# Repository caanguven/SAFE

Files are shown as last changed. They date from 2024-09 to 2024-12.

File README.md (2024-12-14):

# SAFE

Soft robots can adapt to dynamic environments where traditional rigid robots fall short. Existing soft quadruped robots lack effective remote control capabilities and often struggle with maintaining stable locomotion over long distances, limiting their practical application in real-world scenarios. This research addresses the challenges by improving the controllability and reliability of soft quadruped robots for use in search and rescue operations.

I developed the Soft Adaptive Field Explorer (SAFE), a tetherless soft quadruped robot equipped with onboard control interfaces and integrated sensors. A user-controlled web-based interface allows operators to interact with and control SAFE remotely. The integration of sensors such as cameras, inertial measurement units, and absolute rotary encoders optimizes gait performance through closed-loop feedback control. A comparative analysis of soft, rigid, and semi-soft leg materials evaluates their impact on stability, efficiency, and adaptability, identifying the optimal balance for diverse terrains.

This research demonstrates that incorporating the web-based interface and onboard sensor feedback improves the robot’s stability and navigational accuracy. By improving the adaptability and controllability of soft quadruped robots, this work bridges the gap between current soft robot capabilities and potential requirements for use in disaster response applications.

## Project Overview

The Advanced Quadruped project focuses on developing a robust and adaptable quadruped robot, SAFE, designed for challenging environments. The project includes the following key components:

- **Motor Control**: Utilizing Raspberry Pi and motor controllers to achieve precise movement and control of the quadruped's legs.
- **PID Control**: Implementing PID controllers to maintain stable locomotion and optimize gait performance.
- **Sensor Integration**: Incorporating various sensors such as cameras, IMUs, and rotary encoders to provide real-time feedback and enhance control accuracy.
- **Web-Based Interface**: Developing a user-friendly web interface for remote control and monitoring of the robot.

## Project Structure

The project is organized into the following directories and files:

### Directories

- **data_collect/**: Includes code used to collect data while operating the robot.
- **development/**: Includes an interface used at developemnt. By running the main.py you can access the main interface at port 5000. Using this interface we can access to various functionalies of SAFE. This is only for development purposes. Some codes might not work as expected.  
- **motor_controller_dev/**: Includes the directores that includes the motor controller such as square follow, April Tag detectino.
- **web_based_drive/**: Main teleoperated controller of the SAFE. Running main.py should start a fully functional Flask server that will provide IMU Camera and encoder data to user. This is the most optimzated way to operate SAFE. 

## Installation

To run this project, you need to have the following dependencies installed:

- `RPi.GPIO`
- `Adafruit_GPIO`
- `Adafruit_MCP3008`
- `solidpython`

You can install the required Python packages using pip. 

## Usage

To operate the SAFE robot, follow these steps:

1. **Setup**: Ensure all hardware components are properly connected and powered on. Verify that the Raspberry Pi is connected to the same network as your control device.
2. **Start the Server**: Navigate to the `web_based_drive` directory and run `main.py` to start the Flask server.
    ```sh
    cd /path/to/web_based_drive
    python main.py
    ```
3. **Access the Interface**: Open a web browser and navigate to `http://<Raspberry_Pi_IP>:5000` to access the web-based control interface.
4. **Control the Robot**: Use the interface to control the robot's movements, monitor sensor data, and adjust settings as needed.

## Contributing

Contributions to the SAFE project are welcome. If you have suggestions for improvements or new features, please follow these steps:

1. Fork the repository.
2. Create a new branch for your feature or bugfix.
3. Commit your changes and push the branch to your fork.
4. Submit a pull request with a detailed description of your changes.

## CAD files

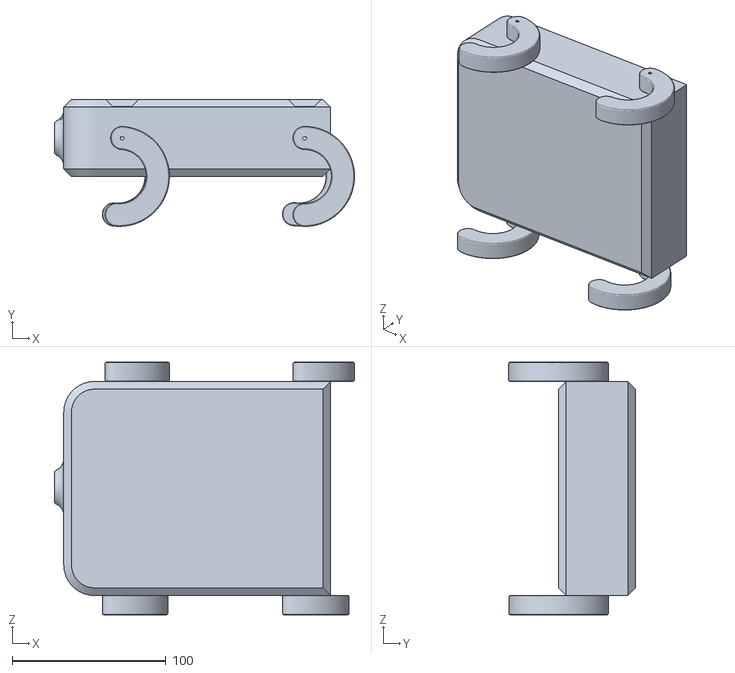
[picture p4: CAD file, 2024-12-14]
web_based_drive/static/model.stl
195.0 x 82.5 x 164.2

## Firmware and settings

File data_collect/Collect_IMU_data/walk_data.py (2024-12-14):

import warnings
import argparse
import sys
import logging
import math
import time
import signal
import os

import RPi.GPIO as GPIO
import busio
import board
import adafruit_bno08x
from adafruit_bno08x.i2c import BNO08X_I2C
import Adafruit_GPIO.SPI as SPI
import Adafruit_MCP3008
import threading

# Suppress specific warnings
warnings.filterwarnings("ignore", category=RuntimeWarning, module="adafruit_blinka.microcontroller.generic_linux.i2c")
warnings.filterwarnings("ignore", category=RuntimeWarning)

# Configure basic logging
logging.basicConfig(
    level=logging.INFO,
    format='%(message)s',
    handlers=[logging.StreamHandler()]
)

# Suppress GPIO warnings
GPIO.setwarnings(False)

# Constants for SPI and ADC
SPI_PORT = 0
SPI_DEVICE = 0
ADC_MAX = 1023
MIN_ANGLE = 0
MAX_ANGLE = 330
SAWTOOTH_PERIOD = 2  # Period in seconds

# GPIO Pins configuration (using BCM numbering)
# Motor 1 (Left Front)
MOTOR1_IN1 = 4
MOTOR1_IN2 = 7
MOTOR1_SPD = 24
MOTOR1_ADC_CHANNEL = 0

# Motor 2 (Right Front)
MOTOR2_IN1 = 5
MOTOR2_IN2 = 25
MOTOR2_SPD = 6
MOTOR2_ADC_CHANNEL = 1

# Motor 3 (Left Rear)
MOTOR3_IN1 = 17
MOTOR3_IN2 = 12
MOTOR3_SPD = 13
MOTOR3_ADC_CHANNEL = 2

# Motor 4 (Right Rear)
MOTOR4_IN1 = 18
MOTOR4_IN2 = 27
MOTOR4_SPD = 19
MOTOR4_ADC_CHANNEL = 3

class SpikeFilter:
    def __init__(self, name):
        self.filter_active = False
        self.last_valid_reading = None
        self.name = name

    def filter(self, new_value):
        if self.filter_active:
            if 150 <= new_value <= 700:
                return None
            else:
                self.filter_active = False
                self.last_valid_reading = new_value
                return new_value
        else:
            if self.last_valid_reading is not None and abs(self.last_valid_reading - new_value) > 300:
                self.filter_active = True
                return None
            else:
                self.last_valid_reading = new_value
                return new_value

    def reset(self):
        self.filter_active = False
        self.last_valid_reading = None

class PIDController:
    def __init__(self, Kp, Ki, Kd, name='PID'):
        self.Kp = Kp
        self.Ki = Ki
        self.Kd = Kd
        self.previous_error = 0
        self.integral = 0
        self.last_time = time.time()
        self.name = name

    def compute(self, error):
        current_time = time.time()
        delta_time = current_time - self.last_time
        if delta_time <= 0.0:
            delta_time = 0.0001

        proportional = self.Kp * error
        self.integral += error * delta_time
        integral = self.Ki * self.integral
        derivative = self.Kd * (error - self.previous_error) / delta_time

        control_signal = proportional + integral + derivative
        self.previous_error = error
        self.last_time = current_time

        return control_signal

    def reset(self):
        self.previous_error = 0
        self.integral = 0
        self.last_time = time.time()

class MotorController:
    def __init__(self, name, in1, in2, pwm, adc_channel, encoder_flipped=False):
        self.name = name
        self.in1 = in1
        self.in2 = in2
        self.pwm = pwm
        self.adc_channel = adc_channel
        self.position = 0
        self.last_valid_position = None
        self.pid = PIDController(Kp=0.8, Ki=0.1, Kd=0.05, name=f'PID-{self.name}')
        self.encoder_flipped = encoder_flipped
        self.spike_filter = SpikeFilter(name)

    def read_position(self, mcp):
        raw_value = mcp.read_adc(self.adc_channel)
        if self.encoder_flipped:
            raw_value = ADC_MAX - raw_value

        filtered_value = self.spike_filter.filter(raw_value)
        if filtered_value is None:
            return self.last_valid_position if self.last_valid_position is not None else 0

        degrees = (filtered_value / ADC_MAX) * 330.0
        self.last_valid_position = degrees
        return degrees

    def set_motor_direction(self, direction):
        if direction == 'forward':
            GPIO.output(self.in1, GPIO.HIGH)
            GPIO.output(self.in2, GPIO.LOW)
        else:
            GPIO.output(self.in1, GPIO.LOW)
            GPIO.output(self.in2, GPIO.HIGH)

    def move_to_position(self, target, mcp):
        try:
            current_position = self.read_position(mcp)
            error = target - current_position

            if error > 165:
                error -= 330
            elif error < -165:
                error += 330

            control_signal = self.pid.compute(error)

            if abs(error) <= 2:
                self.stop_motor()
                return True

            direction = 'forward' if control_signal > 0 else 'backward'
            self.set_motor_direction(direction)
            speed = min(100, max(30, abs(control_signal)))
            self.pwm.ChangeDutyCycle(speed)
            return False
        except Exception as e:
            self.reset()
            return False

    def stop_motor(self):
        GPIO.output(self.in1, GPIO.LOW)
        GPIO.output(self.in2, GPIO.LOW)
        self.pwm.ChangeDutyCycle(0)

    def reset(self):
        self.stop_motor()
        self.pid.reset()
        self.spike_filter.reset()

class MotorGroup:
    def __init__(self, motors, group_phase_difference=0, direction=1):
        self.motors = motors
        self.group_phase_difference = group_phase_difference
        self.direction = direction

    def generate_target_positions(self, base_position):
        target_positions = []
        for motor in self.motors:
            position = (base_position + self.group_phase_difference) % MAX_ANGLE
            if self.direction == -1:
                position = (MAX_ANGLE - position) % MAX_ANGLE
            target_positions.append(position)
        return target_positions

class MotorControlSystem:
    def __init__(self, mcp, mode='walk', enable_correction=False, bno=None, calibration_offsets=None):
        self.mode = mode  # 'walk', 'trot', or 'gallop'
        self.current_direction = 'forward'
        self.lock = threading.Lock()
        self.running = True
        self.mcp = mcp
        self.enable_correction = enable_correction
        self.bno = bno
        self.calibration_offsets = calibration_offsets
        self.YAW_THRESHOLD = 17.0  # degrees
        self.CORRECTION_ANGLE = 17.0  # degrees

        # GPIO setup
        GPIO.setmode(GPIO.BCM)
        GPIO.setup(MOTOR1_IN1, GPIO.OUT)
        GPIO.setup(MOTOR1_IN2, GPIO.OUT)
        GPIO.setup(MOTOR1_SPD, GPIO.OUT)
        GPIO.setup(MOTOR2_IN1, GPIO.OUT)
        GPIO.setup(MOTOR2_IN2, GPIO.OUT)
        GPIO.setup(MOTOR2_SPD, GPIO.OUT)
        GPIO.setup(MOTOR3_IN1, GPIO.OUT)
        GPIO.setup(MOTOR3_IN2, GPIO.OUT)
        GPIO.setup(MOTOR3_SPD, GPIO.OUT)
        GPIO.setup(MOTOR4_IN1, GPIO.OUT)
        GPIO.setup(MOTOR4_IN2, GPIO.OUT)
        GPIO.setup(MOTOR4_SPD, GPIO.OUT)

        # Set up PWM for motor speed control
        self.motor1_pwm = GPIO.PWM(MOTOR1_SPD, 1000)
        self.motor1_pwm.start(0)
        self.motor2_pwm = GPIO.PWM(MOTOR2_SPD, 1000)
        self.motor2_pwm.start(0)
        self.motor3_pwm = GPIO.PWM(MOTOR3_SPD, 1000)
        self.motor3_pwm.start(0)
        self.motor4_pwm = GPIO.PWM(MOTOR4_SPD, 1000)
        self.motor4_pwm.start(0)

        # Initialize motors
        self.motor1 = MotorController("M1", MOTOR1_IN1, MOTOR1_IN2, self.motor1_pwm,
                                      MOTOR1_ADC_CHANNEL, encoder_flipped=False)
        self.motor2 = MotorController("M2", MOTOR2_IN1, MOTOR2_IN2, self.motor2_pwm,
                                      MOTOR2_ADC_CHANNEL, encoder_flipped=True)
        self.motor3 = MotorController("M3", MOTOR3_IN1, MOTOR3_IN2, self.motor3_pwm,
                                      MOTOR3_ADC_CHANNEL, encoder_flipped=False)
        self.motor4 = MotorController("M4", MOTOR4_IN1, MOTOR4_IN2, self.motor4_pwm,
                                      MOTOR4_ADC_CHANNEL, encoder_flipped=True)

        self.motors = {
            'M1': self.motor1,
            'M2': self.motor2,
            'M3': self.motor3,
            'M4': self.motor4
        }

        self.start_time = time.time()

        # Start the control loop in a separate thread
        self.control_thread = threading.Thread(target=self.control_loop, daemon=True)
        self.control_thread.start()

    def set_mode(self, mode):
        with self.lock:
            self.mode = mode

    def generate_sawtooth_position(self):
        elapsed_time = time.time() - self.start_time
        position_in_cycle = (elapsed_time % SAWTOOTH_PERIOD) / SAWTOOTH_PERIOD
        position = (position_in_cycle * MAX_ANGLE) % MAX_ANGLE
        return position

    def configure_motor_groups(self, direction, mode):
        if mode == 'gallop' and direction in ['forward', 'backward']:
            # Gallop gait
            direction_value = 1 if direction == 'forward' else -1
            group1 = MotorGroup(
                motors=[self.motors['M2'], self.motors['M1']],
                group_phase_difference=0,
                direction=direction_value
            )
            group2 = MotorGroup(
                motors=[self.motors['M4'], self.motors['M3']],
                group_phase_difference=180,
                direction=direction_value
            )
            return [group1, group2]
        elif mode == 'trot' and direction in ['forward', 'backward']:
            # Trot gait (similar to normal gait)
            direction_value = 1 if direction == 'forward' else -1
            group1 = MotorGroup(
                motors=[self.motors['M2'], self.motors['M3']],
                group_phase_difference=0,
                direction=direction_value
            )
            group2 = MotorGroup(
                motors=[self.motors['M1'], self.motors['M4']],
                group_phase_difference=180,
                direction=direction_value
            )
            return [group1, group2]
        elif mode == 'walk' and direction in ['forward', 'backward']:
            # Walk gait
            direction_value = 1 if direction == 'forward' else -1
            group1 = MotorGroup(
                motors=[self.motors['M2']],
                group_phase_difference=0,
                direction=direction_value
            )
            group2 = MotorGroup(
                motors=[self.motors['M4']],
                group_phase_difference=90,
                direction=direction_value
            )
            group3 = MotorGroup(
                motors=[self.motors['M1']],
                group_phase_difference=180,
                direction=direction_value
            )
            group4 = MotorGroup(
                motors=[self.motors['M3']],
                group_phase_difference=270,
                direction=direction_value
            )
            return [group1, group2, group3, group4]
        else:
            # Default gait
            direction_value = 1 if direction == 'forward' else -1
            group1 = MotorGroup(
                motors=[self.motors['M2'], self.motors['M3']],
                group_phase_difference=0,
                direction=direction_value
            )
            group2 = MotorGroup(
                motors=[self.motors['M1'], self.motors['M4']],
                group_phase_difference=180,
                direction=direction_value
            )
            return [group1, group2]

    def perform_point_turn(self, turn_direction, angle):
        """
        Perform a point turn to correct the robot's direction.

        :param turn_direction: 'left' or 'right'.
        :param angle: Angle to turn in degrees.
        """
        motor_speed = 70  # Speed for point turn; adjust as needed

        # Configure motors for point turn
        if turn_direction == 'right':
            # Right point turn: Right motors backward, Left motors forward
            self.motors['M1'].set_motor_direction('forward')
            self.motors['M2'].set_motor_direction('backward')
            self.motors['M3'].set_motor_direction('forward')
            self.motors['M4'].set_motor_direction('backward')
        else:
            # Left point turn: Left motors backward, Right motors forward
            self.motors['M1'].set_motor_direction('backward')
            self.motors['M2'].set_motor_direction('forward')
            self.motors['M3'].set_motor_direction('backward')
            self.motors['M4'].set_motor_direction('forward')

        # Set motor speeds
        for motor in self.motors.values():
            motor.pwm.ChangeDutyCycle(motor_speed)

        print(f"\nStarting {turn_direction} point turn of {angle}°")

        # Record initial yaw
        initial_yaw = get_current_yaw(self.bno, self.calibration_offsets)
        if initial_yaw is None:
            print("Failed to get initial yaw for point turn.")
            return

        # Determine target yaw
        if turn_direction == 'right':
            target_yaw = (initial_yaw + angle) % 360
        else:
            target_yaw = (initial_yaw - angle + 360) % 360

        if target_yaw > 180:
            target_yaw -= 360  # Convert to range [-180, 180]

        # Main turn loop
        while True:
            current_yaw = get_current_yaw(self.bno, self.calibration_offsets)
            if current_yaw is None:
                print("Yaw reading failed during point turn.")
                break

            # Calculate turned angle
            if turn_direction == 'right':
                turned_angle = (current_yaw - initial_yaw + 360) % 360
                if turned_angle > 180:
                    turned_angle -= 360
            else:
                turned_angle = (initial_yaw - current_yaw + 360) % 360
                if turned_angle > 180:
                    turned_angle -= 360

            print(f"Point Turn - Current yaw: {current_yaw:.2f}°, Turned: {turned_angle:.2f}°    ", end='\r')

            if abs(turned_angle) >= angle:
                print(f"\nPoint turn completed! Final yaw: {current_yaw:.2f}°")
                break

            time.sleep(0.05)

        # Stop motors after point turn
        for motor in self.motors.values():
            motor.stop_motor()
        time.sleep(0.5)  # Brief pause after turn

    def control_loop(self):
        while self.running:
            with self.lock:
                direction = self.current_direction
                mode = self.mode

            # Yaw correction
            if self.enable_correction and self.bno and self.calibration_offsets:
                current_yaw = get_current_yaw(self.bno, self.calibration_offsets)
                if current_yaw is None:
                    logging.warning("Yaw reading failed. Skipping correction.")
                else:
                    if current_yaw > self.YAW_THRESHOLD:
                        logging.info(f"Yaw deviation: {current_yaw:.2f}°, performing corrective right point turn")
                        self.perform_point_turn('left', self.CORRECTION_ANGLE)
                    elif current_yaw < -self.YAW_THRESHOLD:
                        logging.info(f"Yaw deviation: {current_yaw:.2f}°, performing corrective left point turn")
                        self.perform_point_turn('right', self.CORRECTION_ANGLE)
                    else:
                        logging.info(f"Yaw deviation: {current_yaw:.2f}°, maintaining straight path")

            motor_groups = self.configure_motor_groups(direction, mode)
            base_position = self.generate_sawtooth_position()

            for group in motor_groups:
                targets = group.generate_target_positions(base_position)
                for motor, target in zip(group.motors, targets):
                    motor.move_to_position(target, self.mcp)

            time.sleep(0.02)  # 20 ms delay

    def stop(self):
        self.running = False
        self.control_thread.join()
        for motor in self.motors.values():
            motor.stop_motor()

        self.motor1_pwm.stop()
        self.motor2_pwm.stop()
        self.motor3_pwm.stop()
        self.motor4_pwm.stop()
        GPIO.cleanup()

def quaternion_to_euler(quat_i, quat_j, quat_k, quat_real):
    """
    Convert quaternion to Euler angles (roll, pitch, yaw)
    """
    try:
        # Roll (x-axis rotation)
        sinr_cosp = 2 * (quat_real * quat_i + quat_j * quat_k)
        cosr_cosp = 1 - 2 * (quat_i * quat_i + quat_j * quat_j)
        roll = math.atan2(sinr_cosp, cosr_cosp)

        # Pitch (y-axis rotation)
        sinp = 2 * (quat_real * quat_j - quat_k * quat_i)
        if abs(sinp) >= 1:
            pitch = math.copysign(math.pi / 2, sinp)  # Use 90 degrees if out of range
        else:
            pitch = math.asin(sinp)

        # Yaw (z-axis rotation)
        siny_cosp = 2 * (quat_real * quat_k + quat_i * quat_j)
        cosy_cosp = 1 - 2 * (quat_j * quat_j + quat_k * quat_k)
        yaw = math.atan2(siny_cosp, cosy_cosp)

        # Convert to degrees
        roll_deg = math.degrees(roll)
        pitch_deg = math.degrees(pitch)
        yaw_deg = math.degrees(yaw)

        return roll_deg, pitch_deg, yaw_deg

    except Exception as e:
        print(f"Error in quaternion conversion: {str(e)}")
        return None, None, None

def setup_imu():
    """Initialize IMU with retry mechanism"""
    max_retries = 3
    retry_delay = 2  # seconds

    for attempt in range(max_retries):
        try:
            print(f"Attempting to initialize IMU (attempt {attempt + 1}/{max_retries})...")

            i2c = busio.I2C(board.SCL, board.SDA, frequency=100000)
            time.sleep(0.5)

            bno = BNO08X_I2C(i2c)
            time.sleep(1)

            bno.enable_feature(adafruit_bno08x.BNO_REPORT_ROTATION_VECTOR)
            time.sleep(0.5)

            # Verify sensor
            quat = bno.quaternion
            if quat is None:
                raise RuntimeError("Unable to read quaternion data")

            # Test quaternion conversion
            roll, pitch, yaw = quaternion_to_euler(*quat)
            if any(x is None for x in [roll, pitch, yaw]):
                raise RuntimeError("Invalid quaternion conversion")

            print("IMU initialized successfully")
            return bno

        except Exception as e:
            print(f"Attempt {attempt + 1} failed: {str(e)}")
            if attempt < max_retries - 1:
                print(f"Retrying in {retry_delay} seconds...")
                time.sleep(retry_delay)
            else:
                print("IMU initialization failed after all attempts")
                raise

def calibrate_imu(bno):
    """Calibrate IMU with improved error handling"""
    print("\nCalibrating IMU (stay still)...")
    samples = []
    max_samples = 50
    timeout = 30  # seconds
    start_time = time.time()

    while len(samples) < max_samples and time.time() - start_time < timeout:
        try:
            if len(samples) % 10 == 0 and len(samples) != 0:
                print(f"Collecting samples... {len(samples)}/{max_samples}", end='\r')
            quat = bno.quaternion

            if quat is not None and len(quat) == 4:
                roll, pitch, yaw = quaternion_to_euler(*quat)
                if None not in (roll, pitch, yaw) and not any(math.isnan(x) for x in [roll, pitch, yaw]):
                    samples.append((roll, pitch, yaw))
            else:
                print("\nInvalid quaternion reading, retrying...")
                time.sleep(0.5)

        except Exception as e:
            print(f"\nError during calibration: {str(e)}")
            time.sleep(0.5)

    if len(samples) >= max_samples / 2:
        # Compute average offsets for roll, pitch, yaw
        sum_roll = sum(sample[0] for sample in samples)
        sum_pitch = sum(sample[1] for sample in samples)
        sum_yaw = sum(sample[2] for sample in samples)

        calibration_offset = {
            'roll': sum_roll / len(samples),
            'pitch': sum_pitch / len(samples),
            'yaw': sum_yaw / len(samples)
        }

        print(f"\nCalibration complete. Reference angles:")
        print(f"Roll offset: {calibration_offset['roll']:.2f}°")
        print(f"Pitch offset: {calibration_offset['pitch']:.2f}°")
        print(f"Yaw offset: {calibration_offset['yaw']:.2f}°")
        return calibration_offset
    else:
        raise RuntimeError(f"Failed to collect enough valid samples (got {len(samples)} of {max_samples})")

def get_current_euler(bno, calibration_offsets, retries=3):
    """Get current Euler angles with calibration offsets"""
    for _ in range(retries):
        try:
            quat = bno.quaternion
            if quat is not None and len(quat) == 4 and not any(math.isnan(x) for x in quat):
                roll, pitch, yaw = quaternion_to_euler(*quat)
                if None not in (roll, pitch, yaw):
                    # Apply calibration offsets
                    roll_adjusted = roll - calibration_offsets['roll']
                    pitch_adjusted = pitch - calibration_offsets['pitch']
                    yaw_adjusted = yaw - calibration_offsets['yaw']

                    # Normalize angles to [-180, 180]
                    roll_adjusted = (roll_adjusted + 180) % 360 - 180
                    pitch_adjusted = (pitch_adjusted + 180) % 360 - 180
                    yaw_adjusted = (yaw_adjusted + 180) % 360 - 180

                    return roll_adjusted, pitch_adjusted, yaw_adjusted
        except Exception:
            time.sleep(0.1)
    return None, None, None

def get_current_yaw(bno, calibration_offsets, retries=3):
    """Get current yaw with calibration offset"""
    roll, pitch, yaw = get_current_euler(bno, calibration_offsets, retries)
    return yaw
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

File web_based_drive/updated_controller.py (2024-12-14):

import RPi.GPIO as GPIO
import time
import Adafruit_GPIO.SPI as SPI
import Adafruit_MCP3008
import threading
import logging
import numpy as np

# Configure Logging
logging.basicConfig(level=logging.DEBUG,
                    format='%(asctime)s [%(levelname)s] %(message)s',
                    handlers=[
                        logging.FileHandler("motor_control.log"),
                        logging.StreamHandler()
                    ])

# Constants
SPI_PORT = 0
SPI_DEVICE = 0
ADC_MAX = 1023
MIN_ANGLE = 0
MAX_ANGLE = 360  # Changed to 360 as per thesis
SAWTOOTH_PERIOD = 2  # Period in seconds

# Motor GPIO Pin Configuration
MOTOR_CONFIGS = {
    'M1': {'IN1': 4, 'IN2': 7, 'SPD': 24, 'ADC': 0, 'FLIP': False},
    'M2': {'IN1': 5, 'IN2': 25, 'SPD': 6, 'ADC': 1, 'FLIP': True},
    'M3': {'IN1': 17, 'IN2': 12, 'SPD': 13, 'ADC': 2, 'FLIP': False},
    'M4': {'IN1': 18, 'IN2': 27, 'SPD': 19, 'ADC': 3, 'FLIP': True}
}

class SpikeFilter:
    def __init__(self, name, threshold=300):
        self.name = name
        self.threshold = threshold
        self.last_valid_reading = None
        self.filter_active = False
        self.dead_zone_lower = 150
        self.dead_zone_upper = 700

    def filter(self, new_value):
        # Dead zone detection
        if self.dead_zone_lower <= new_value <= self.dead_zone_upper:
            logging.debug(f"{self.name} SpikeFilter: Dead zone detected at {new_value}")
            return None

        # Spike detection
        if self.last_valid_reading is not None:
            if abs(self.last_valid_reading - new_value) > self.threshold:
                logging.debug(f"{self.name} SpikeFilter: Spike detected: {new_value}")
                return None

        self.last_valid_reading = new_value
        return new_value

    def reset(self):
        self.last_valid_reading = None
        self.filter_active = False

class PIDController:
    def __init__(self, Kp, Ki, Kd, name='PID'):
        self.Kp = Kp
        self.Ki = Ki
        self.Kd = Kd
        self.previous_error = 0
        self.integral = 0
        self.last_time = time.time()
        self.name = name
        self.max_integral = 100  # Prevent integral windup

    def compute(self, error, dt=None):
        if dt is None:
            current_time = time.time()
            dt = current_time - self.last_time
            self.last_time = current_time

        if dt <= 0:
            dt = 0.001

        # Proportional term
        P = self.Kp * error

        # Integral term with anti-windup
        self.integral += error * dt
        self.integral = max(min(self.integral, self.max_integral), -self.max_integral)
        I = self.Ki * self.integral

        # Derivative term
        D = self.Kd * (error - self.previous_error) / dt
        self.previous_error = error

        # Calculate total control signal
        control_signal = P + I + D
        
        logging.debug(f"{self.name} PID: P={P:.2f}, I={I:.2f}, D={D:.2f}, total={control_signal:.2f}")
        
        return control_signal

    def reset(self):
        self.previous_error = 0
        self.integral = 0
        self.last_time = time.time()

class MotorController:
    def __init__(self, name, in1, in2, pwm, adc_channel, encoder_flipped=False):
        self.name = name
        self.in1 = in1
        self.in2 = in2
        self.pwm = pwm
        self.adc_channel = adc_channel
        self.encoder_flipped = encoder_flipped
        
        # Controller parameters
        self.pid = PIDController(Kp=0.8, Ki=0.1, Kd=0.05, name=f'PID-{name}')
        self.spike_filter = SpikeFilter(name)
        
        # Dead zone and rate limiting parameters
        self.dead_zone_active = False
        self.dead_zone_speed_limit = 50  # 50% speed limit in dead zone
        self.last_control_signal = 0
        self.max_rate_change = 10  # Maximum change in control signal per iteration
        self.slowdown_threshold = 20  # Degrees
        
        # Position tracking
        self.last_valid_position = None
        self.initial_position = None
        self.startup_complete = False
        
        # Performance monitoring
        self.performance_data = {
            'timestamps': [],
            'positions': [],
            'targets': [],
            'control_signals': []
        }

    def read_position(self, mcp):
        raw_value = mcp.read_adc(self.adc_channel)
        
        if self.encoder_flipped:
            raw_value = ADC_MAX - raw_value
            
        filtered_value = self.spike_filter.filter(raw_value)
        
        if filtered_value is None:
            self.dead_zone_active = True
            return 0 if self.last_valid_position is None else self.last_valid_position
            
        self.dead_zone_active = False
        degrees = (filtered_value / ADC_MAX) * MAX_ANGLE
        self.last_valid_position = degrees
        
        # Handle initial position reading
        if self.initial_position is None:
            self.initial_position = degrees
            
        return degrees

    def limit_rate_of_change(self, new_signal, max_change):
        change = new_signal - self.last_control_signal
        if abs(change) > max_change:
            change = max_change if change > 0 else -max_change
        return self.last_control_signal + change

    def move_to_position(self, target, mcp):
        try:
            current_time = time.time()
            current_position = self.read_position(mcp)
            
            # Smooth startup transition
            if not self.startup_complete:
                target = self.smooth_startup(target, current_position)
            
            # Calculate error
            error = target - current_position
            if abs(error) > MAX_ANGLE/2:
                error = error - np.sign(error) * MAX_ANGLE

            # Generate control signal
            control_signal = self.pid.compute(error)
            
            # Apply rate limiting
            max_change = self.max_rate_change
            if self.dead_zone_active:
                max_change /= 2
            control_signal = self.limit_rate_of_change(control_signal, max_change)
            
            # Apply speed limits and adjustments
            if self.dead_zone_active:
                control_signal = min(abs(control_signal), self.dead_zone_speed_limit) * np.sign(control_signal)
            elif abs(error) < self.slowdown_threshold:
                reduction_factor = abs(error) / self.slowdown_threshold
                control_signal *= reduction_factor
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

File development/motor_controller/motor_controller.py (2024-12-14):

import time
import threading

class MotorController:
    def __init__(self, motor, pid_controller, adc_reader, channel, spike_filter, sawtooth_generator, config, name='Motor'):
        self.motor = motor
        self.pid_controller = pid_controller
        self.adc_reader = adc_reader
        self.channel = channel
        self.spike_filter = spike_filter
        self.sawtooth_generator = sawtooth_generator
        self.config = config
        self.name = name  # For logging purposes

        # Variables for state
        self.in_dead_zone = False
        self.last_valid_control_signal = 0
        self.average_speed_before_dead_zone = 0
        self.speed_samples = []
        self.dead_zone_start_time = None
        self.estimated_position = None
        self.last_degrees_value = None
        self.last_time = time.time()  # Initialize last_time

        # Store initial_angle for initialization phase
        self.initial_angle = self.sawtooth_generator.initial_angle  # Ensure this attribute exists

        # Initialization event
        self.initialized_event = threading.Event()

    def map_potentiometer_value_to_degrees(self, value):
        # Potentiometer values range from 0 to 1023
        # Map to 0 to 330 degrees (since the potentiometer only reads up to 330°)
        return value * (330 / 1023)

    def calculate_error(self, set_position, current_angle, direction='reverse'):
        if direction == 'reverse':
            # Reverse logic: calculate error for reverse motion
            error = (current_angle - set_position + 360) % 360
            if error > 180:
                error = error - 360
        else:
            # Default forward error calculation
            error = (set_position - current_angle + 360) % 360
            if error > 180:
                error = error - 360

        # Do not clamp errors to zero for reverse; they should remain negative or positive
        return error

    def pid_control_motor(self, degrees_value, set_position, direction='forward'):
        DEAD_ZONE_DEG_START = self.config['dead_zone_start']
        OFFSET = self.config['offset']
        slowdown_threshold = self.config['slowdown_threshold']
        max_control_change = self.config['max_control_change']

        current_time = time.time()
        delta_time = current_time - self.last_time
        self.last_time = current_time  # Update last_time here

        if degrees_value is None:
            print(f"{self.name}: degrees_value is None, setting it to 0.0°")
            degrees_value = 0.0  # Default to 0 if degrees_value is None

        # Calculate error based on direction (forward or reverse)
        error = self.calculate_error(set_position, degrees_value, direction)

        # Update set point in PID controller
        self.pid_controller.set_point = set_position

        # Compute control signal using PID controller
        control_signal = self.pid_controller.compute(degrees_value)

        # Apply rate limiter to control signal
        control_signal_change = control_signal - self.last_valid_control_signal
        if abs(control_signal_change) > max_control_change:
            control_signal = self.last_valid_control_signal + max_control_change * (1 if control_signal_change > 0 else -1)

        # Clamp control signal to -100 to 100
        control_signal = max(-100, min(100, control_signal))
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

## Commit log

2024-02-26 camera added
2024-04-25 reading with voltage
2024-09-13 Adding motor controller v1
    * tsting motor 2
    * changs in motor_control
    * motor fixed, adc controller in progress
    * added p_controller
    * fixing map potentiometer function
    * adding shortest path logic
    * updated p_controller
    * only forward logic
    * pid controller added
    * changed direction
    * added CLI support
    * chnaged direction
    * added software filter
    * removed shortest path
    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
    [motor_control.py, motor_test.py, pid_controller.py]
2024-09-17 UI bidirectional (#2)
    * cleaning up the repo
    * added motor_control
    * update
    * update
    * updated port
    * update
    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
2024-09-17 updated UI motor_control
2024-09-17 camera added (#3)
2024-09-18 Gyro and gyro UI updated (#4)
    * aded gyro html
    * aded gyro html
    * added STL
    * added STL
    * removed disable
    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
2024-10-04 Control center (#5)
    * new UI
    * change in location
    * fix white space
    * fix white space
    * fix white space
    * fix white space
    * added empty space
    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
    [main.py]
2024-12-14 Clean Up and updated ReadME (#6)
    * WIP
    * WIP
    * WIP
    * WIP
    * WIP
    * WIP
    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
    [model.stl]
